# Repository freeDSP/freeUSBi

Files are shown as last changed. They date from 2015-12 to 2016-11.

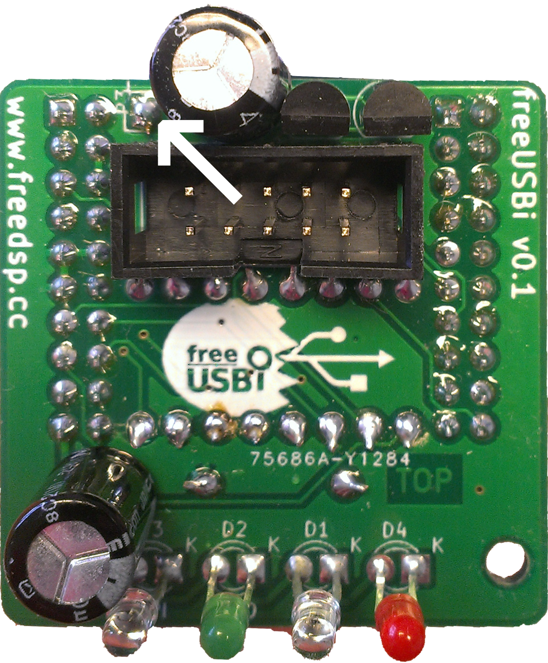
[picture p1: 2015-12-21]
DOCUMENTATION/PICTURES/5V oben.png

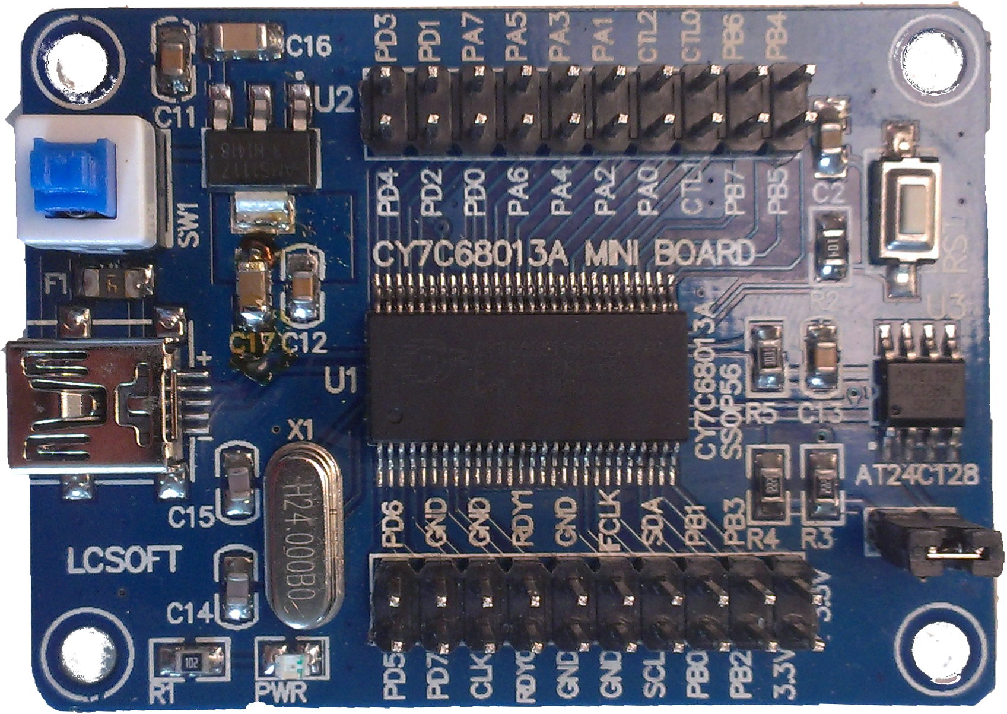
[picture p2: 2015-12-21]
DOCUMENTATION/PICTURES/cypress.png

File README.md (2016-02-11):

# freeUSBi

BOARD STATUS: READY TO BE BUILT

MAIN COORDINATOR: [thebadseeds](https://github.com/thebadseeds)

The freeUSBi is a low-budget real-time programming device for the freeDSP and other DSP boards from Analog Devices. It is based on a CY7C68013A MINI BOARD combined with an adapter PCB (printed circuit board) that adds the possibility of realtime programming.
It has the same features as the Analog Devices USB interface (EVAL-ADUSB2EBZ), such as changing parameters while already using the freeDSP or easy changes of the schematic in SigmaStudio. You also can write your program to the EEPROM.

Please refer to the documentation for more information.

## License

This work and all other materials under https://github.com/freeDSP are licensed under a <a rel="license" href="http://creativecommons.org/licenses/by-sa/4.0/legalcode">Creative Commons Attribution Share-Alike 4.0 license</a>. This allows for both personal and commercial derivative works, as long as they credit freeDSP and release their designs under the same license.

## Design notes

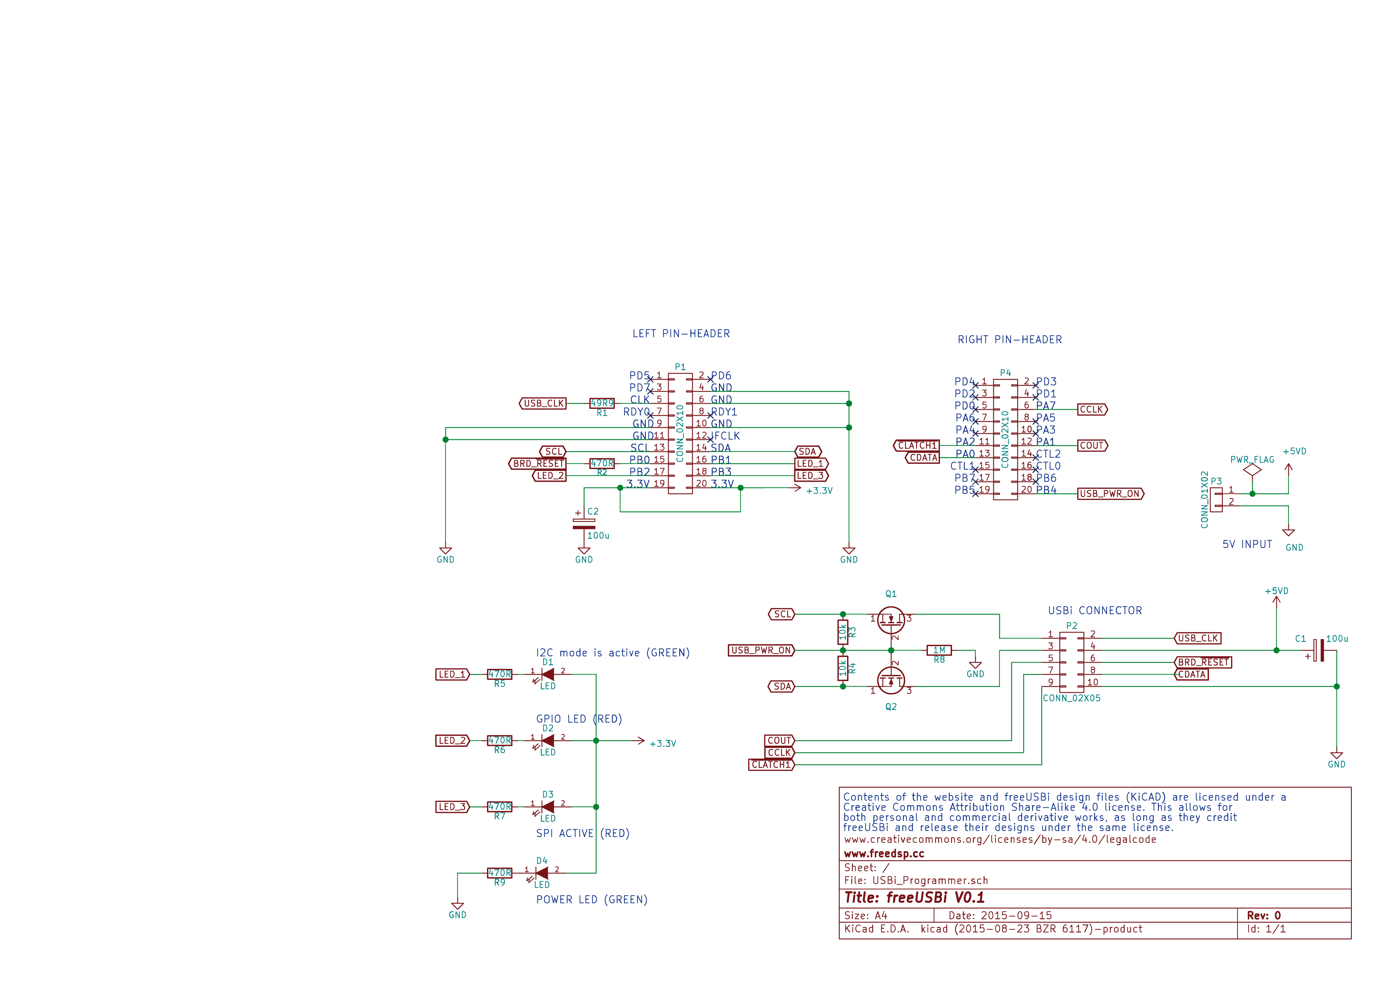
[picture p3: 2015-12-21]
DOCUMENTATION/PICTURES/SchematicUSBi.png

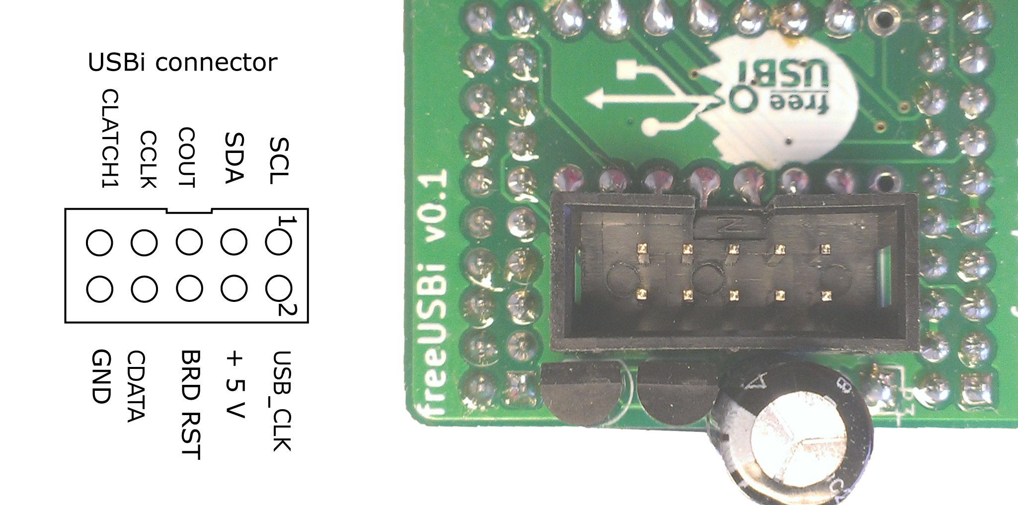
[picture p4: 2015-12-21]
DOCUMENTATION/PICTURES/connector.png

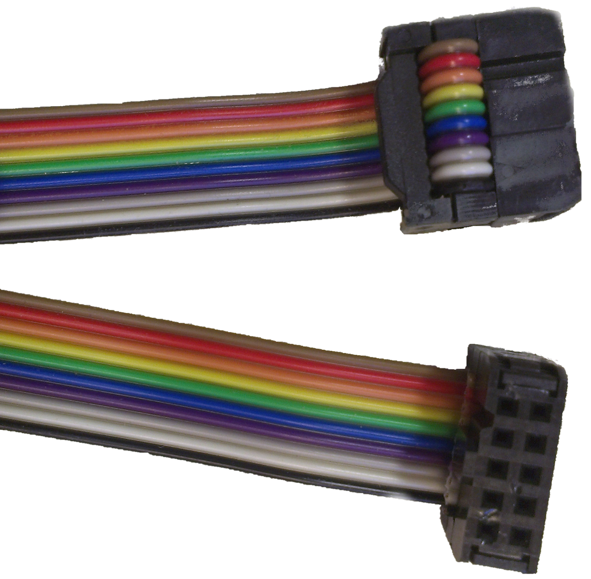
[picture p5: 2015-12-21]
DOCUMENTATION/PICTURES/kabel.png

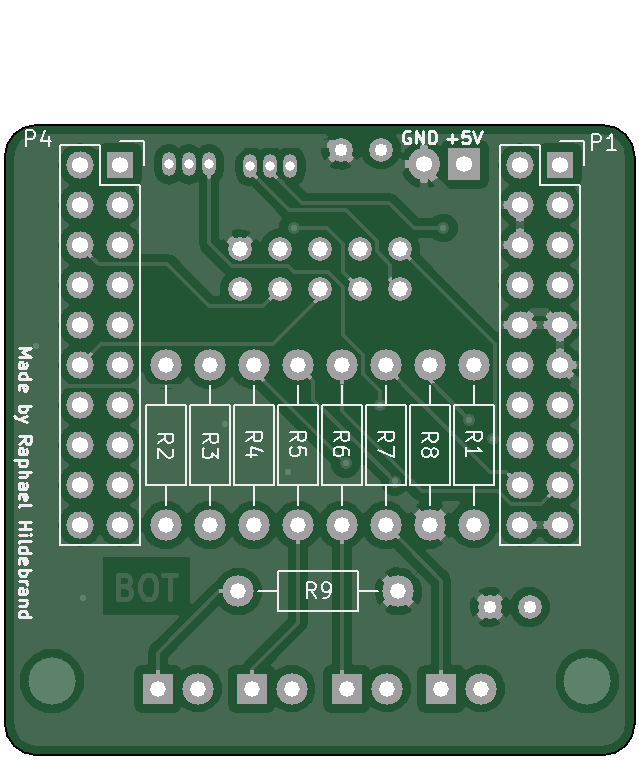
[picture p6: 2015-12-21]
DOCUMENTATION/PICTURES/bottom.png

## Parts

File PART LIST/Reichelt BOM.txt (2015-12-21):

https://secure.reichelt.de/index.html?&ACTION=20&AWKID=1109732&PROVID=2084

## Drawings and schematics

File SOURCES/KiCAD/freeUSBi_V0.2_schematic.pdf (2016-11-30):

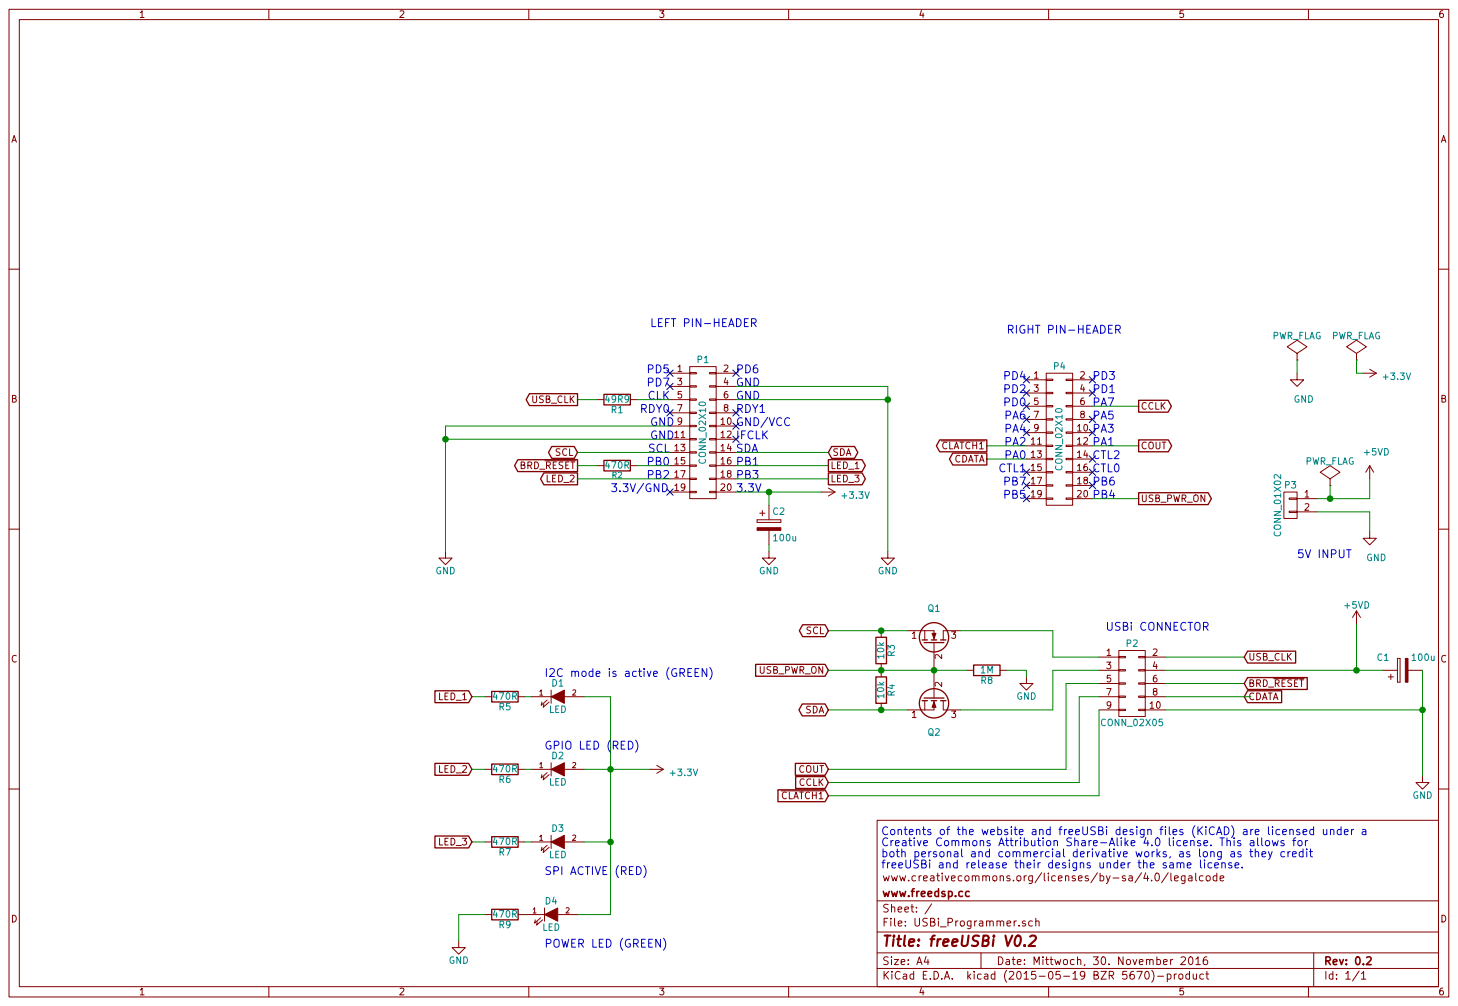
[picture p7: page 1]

I2C mode is active (GREEN)

Contents of the website and freeUSBi design files (KiCAD) are licensed under a
Creative Commons Attribution Share-Alike 4.0 license. This allows for
both personal and commercial derivative works, as long as they credit
freeUSBi and release their designs under the same license.
www.creativecommons.org/licenses/by-sa/4.0/legalcode
File: USBi_Programmer.sch Sheet: / www.freedsp.cc

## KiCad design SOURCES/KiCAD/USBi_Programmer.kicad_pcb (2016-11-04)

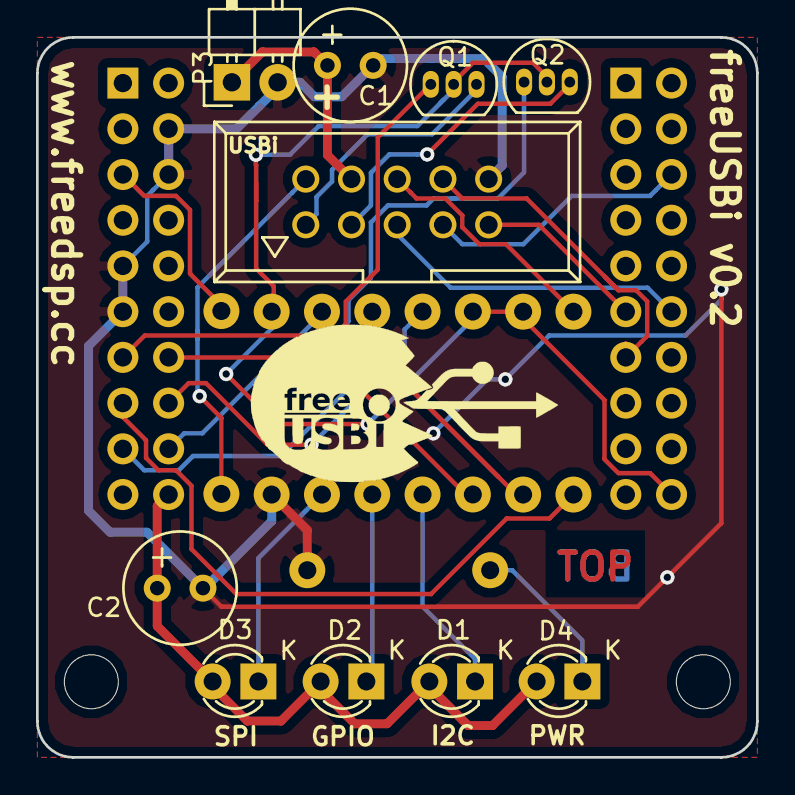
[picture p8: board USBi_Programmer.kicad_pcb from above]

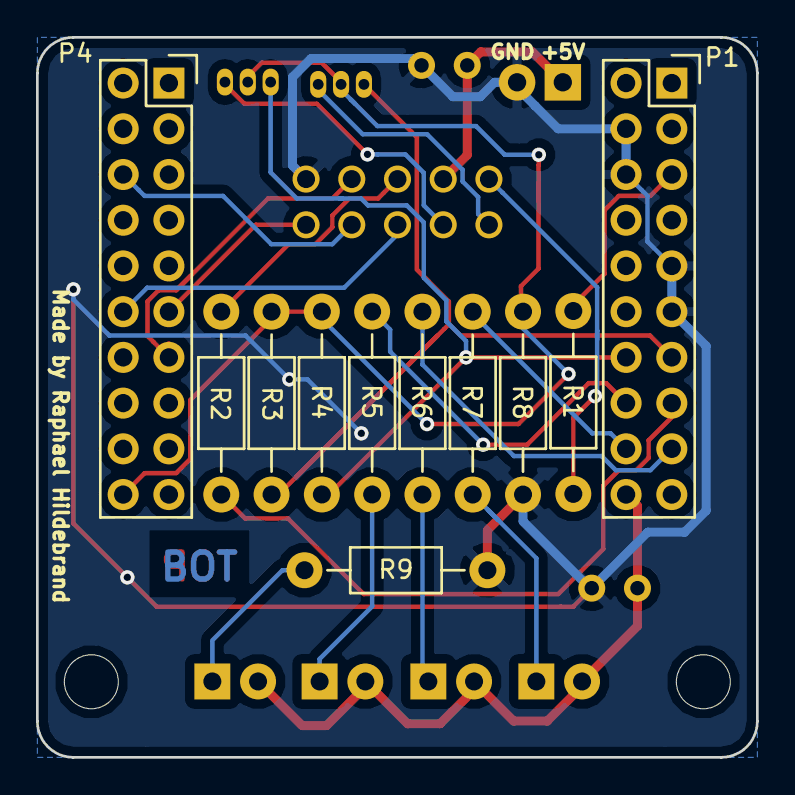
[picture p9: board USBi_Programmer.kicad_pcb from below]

Board: 2 copper layers, 40.0 x 40.0 mm, 21 parts (11 on the bottom side), 23 nets.

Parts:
C1, C2: 100u; Elko_vert_11.2x6.3mm_RM2.5_CopperClear
D1, D2, D3, D4: LED; LED-3MM
P1, P4: CONN_02X10; Socket_Strip_Straight_2x10
P2: CONN_02X05; VASCH5x2
P3: CONN_01X02; Pin_Header_Angled_1x02
Q1, Q2: Q_NMOS_DGS; TO-92_Inline_Narrow_Oval
R1: 49R9; Resistor_Horizontal_RM10mm
R2, R5, R6, R7, R9: 470R; Resistor_Horizontal_RM10mm
R3, R4: 10k; Resistor_Horizontal_RM10mm
R8: 1M; Resistor_Horizontal_RM10mm

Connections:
+3V3: C2.1, D1.2, D2.2, D3.2, D4.2, P1.20
+5VD: C1.1, P2.4, P3.1
BRD_~RESET: P2.6, R2.2
CCLK: P2.7, P4.6
CDATA: P2.8, P4.13
COUT: P2.5, P4.12
GND: C1.2, C2.2, P1.4, P1.6, P1.9, P1.11, P2.10, P3.2, R8.1, R9.2
LED_1: P1.16, R5.2
LED_2: P1.17, R6.2
LED_3: P1.18, R7.2
unnamed: D1.1, R5.1
unnamed: D2.1, R6.1
unnamed: D3.1, R7.1
unnamed: D4.1, R9.1
unnamed: P1.5, R1.1
unnamed: P1.15, R2.1
unnamed: P2.1, Q1.3
unnamed: P2.3, Q2.3
SCL: P1.13, Q1.1, R3.1
SDA: P1.14, Q2.1, R4.2
USB_CLK: P2.2, R1.2
USB_PWR_ON: P4.20, Q1.2, Q2.2, R3.2, R4.1, R8.2
~CLATCH1: P2.9, P4.11

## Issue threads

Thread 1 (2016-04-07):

Improve compability with china USBi-boards

sudlud, 2016-04-07:
- there're 2 different versions of the china mainboard used with freeUSBi
  *\* as mentioned in the _freeUSBi getting started guide_
- to improve compability, one VCC and GND pin of the left pinheader should be disconnected from the pinheader
  *\* refer to _freeUSBi getting started guide_ for the actual pin positions
- it's not necessary that these pins are connected on the pinheader, there're several other VCC / GND - connections to supply the freeUSBi board
- Then the freeUSBi is fully compatible with both versions of china boards

sudlud, 2016-11-30:
Fixed with release-0.2
(5f67d05)

The 2 critical pins were disconnected from the corresponding pinheader

Closed 2016-11-30.

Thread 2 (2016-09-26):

Win 7 x64  drivers won't install

steeley, 2016-09-26:
Following the instructions in the Google docs EXACTLY does not appear to work for W7x64 . Windows device manager just says "could not find driver software for your device"

lsfuchs, 2016-12-29:
Same problem but with Win7 X86 version.

Is there anybody who has a solution?

sudlud, 2016-12-30:
This could be a user-specific issue, the drivers have been tested on many win7 x86 and win7 x64 systems successfully.

Maybe the overall driver-setup-situation of your PC is messed up?

You need to cleanly remove any drivers that were assigned to the freeUSBi before performing the driver installation steps provided by the freeUSBi user guide.

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

sudlud, 2016-12-30:
I also just realized another thing, that we didn't mention in the freeUSBi getting Started Guide yet:

There's a Cypress board with 1 jumper and 2 jumpers.

You MUST remove the jumper if you're using the cypress board with 1 Jumper, otherwise the module might start in the wrong mode and therefore communicate a different USB device to the PC it's connected to.

(On the cypress board with 2 jumpers both jumpers should be 'Don't Care'.)

lsfuchs, 2017-01-01:
Thanks for the answer.

I even have 1 board with one jumper and one with 2 jumpers. Both respond equally. Same message "could not find driver software for your device".

As described in the manual for each trial I removed the jumpers.

srechenb, 2017-04-24:
I'm having the same driver installation issue under Win XP SP3. The cyusb3.inf file has a couple of problems - the reference to the coinstaller file is incorrect, and there is a weird EOL entry in line 39 which may also be incorrect.  All that being said, I still cannot get the driver installed correctly even after trying to fix these INF file problems.

Deinstalling and re-installing SigmaStudio also hasn't helped as suggested by some.  Any ideas how this can be fixed?

srechenb, 2017-04-24:
How should one "cleanly remove" a previous driver installation?  Is the use of driver deinstallation in the device manager sufficient?

the-powl, 2018-08-30:
I just faced the same problem but then I figured out my "own" mistake. When you try to download the .inf file from github, firefox tends to save it do a html-file which doesn't contain the original file data. You have to navigate all the way through till you get to download the "raw" file. Then it worked for me. So if you only get an .inf.html file it won't work! Check that!

Hope that helps anyone! =)

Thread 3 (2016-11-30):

Mounting holes don't fit main board

sudlud, 2016-11-30:
This issue is still present in the current release-0.2

The mounting holes of the freeUSBi PCB are not aligned to the main cypress board that its connected to.

This should be fixed in a future revision.

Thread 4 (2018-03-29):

Driver installation on Windows 8 and 7 does not work

DO1SKU, 2018-03-29:
On both operating systems, this error message appears: The hash value for the file is not in the specified catalog file.

My approach:
1. Board connected to computer
2. Copy file ADI_USBi.spt into the driver folder of the appropriate system
3. Start the driver update with the Device Manager
4. No driver is found with path to the driver folder
5. Even with direct specification of the cyusb3.inf two drivers / device types appear and no one works..

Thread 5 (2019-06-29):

Windows10 FreeUSBi Driver has Incorrect Signature Issue

CyberPit, 2019-06-29:
When installing FreeUSBi driver on Windows10, installation will be denied by security reason.
I guess there are two ways to install....

1. Disable Windows10 Driver Signature Enforcement.
2.Use Signed Driver

I found 2nd solution solver's web page...
https://www.diemaker.de/2017/08/11/suredsp-freeusbi-treiber-signieren/

Cysign, 2020-07-08:
Same here....still couldn't get this shitty MS Windows 10 using the driver.
Time to think about using linux...if there'd only be an alternative for Photoshop... :(

Cysign, 2020-07-13:
MakeCert.exe is deprecated: https://docs.microsoft.com/en-us/windows/win32/seccrypto/makecert

MS new tool suggestion is using the PowerShell and New-SelfSignedCertificate: https://docs.microsoft.com/en-us/powershell/module/pkiclient/new-selfsignedcertificate?view=win10-ps

But still I couldn't figure out how it works...

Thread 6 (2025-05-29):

Windows 10 simple freeUSBi installation method

Gitreposuser, 2025-05-29:
1. Connect programmer with dsp to usb port. Prepare driver as told in base instruction.
2. Open command prompt as administrator.
3. Execute "bcdedit /set testsigning on"
4. Reboot your PC.
5. In Device manager manually instal driver.
6. Execute "bcdedit /set testsigning off" to set back setting.
7. Enjoy.

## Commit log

2015-12-21 folder structure + initial sources V0.1
    added folder structure + initial sources V0.1
    [USBi_Programmer-B_Cu.gbl, USBi_Programmer-B_Mask.gbs, USBi_Programmer-B_SilkS.gbo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]
2016-04-21 Add drivers for Win10.
2016-11-04 V0.2: Move holes & disconnect 2 pins from pinheader
    These pins usually had to be cut out from the main cypress board.
    Now that they're disconnected, there's no need anymore to cut them.
    Also the mounting holes didn't fit exactly to the holes on the cypress main board.
    [USBi_Programmer-B_Cu.gbl, USBi_Programmer-B_Mask.gbs, USBi_Programmer-B_SilkS.gbo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]
2016-11-30 Update schematic title to 'freeUSBi V0.2'
    [USBi_Programmer.sch]
2016-11-30 Add PDF for freeUSBi V0.2 schematic
2016-11-30 Add PDF for freeUSBi V0.1 schematic
    This PDF is added for reference only. All
    new freeUSBi should be built with V0.2 or
    newer PCBs.
2016-11-30 Add gitignore & gitattributes
    These files were derived from the corresponding files
    within the freeDSP-KiCad-Library Github repository.
